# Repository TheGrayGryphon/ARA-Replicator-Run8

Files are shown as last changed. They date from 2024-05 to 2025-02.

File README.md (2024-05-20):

This is a complete build of a miniature rail-stand for use with railroad simulators.

Included in this repo:
1. Arduino IDE project for the hardware interface written found in the *miniRD_fw* directory.
2. Host "daemon" Python code used to send UDP data to the train simulator software known as Run8 (*Main.py* and *Run8.py*) - see *requirements.txt* for library dependencies.
3. KiCad project (right now, just a schematic) found in the *miniRDkicad* directory which details the electronics for the user controls.
4. Finally, some details on the mechanical bits including a layout of the button / lever mapping and links to the OnShape 3D model used to 3D-print the stand itself: https://cad.onshape.com/documents/ee68d1fb4ee2b8880d44aae3/w/7c6829b5f97449183b040dd5/e/efcd98333ec3d0d73e2c39b0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

See https://youtu.be/2jeVMYr9WaY?si=O1BfRgeKVzKorJtD for early demo.



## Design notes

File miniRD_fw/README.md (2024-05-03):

# MiniRD arduino "firmware"
 
Handles scanning the hardware (analog / digital) and interfacing to MiniRD daemon via serial port

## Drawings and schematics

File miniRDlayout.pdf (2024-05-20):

## Train brake lever

## Dynamic brake lever

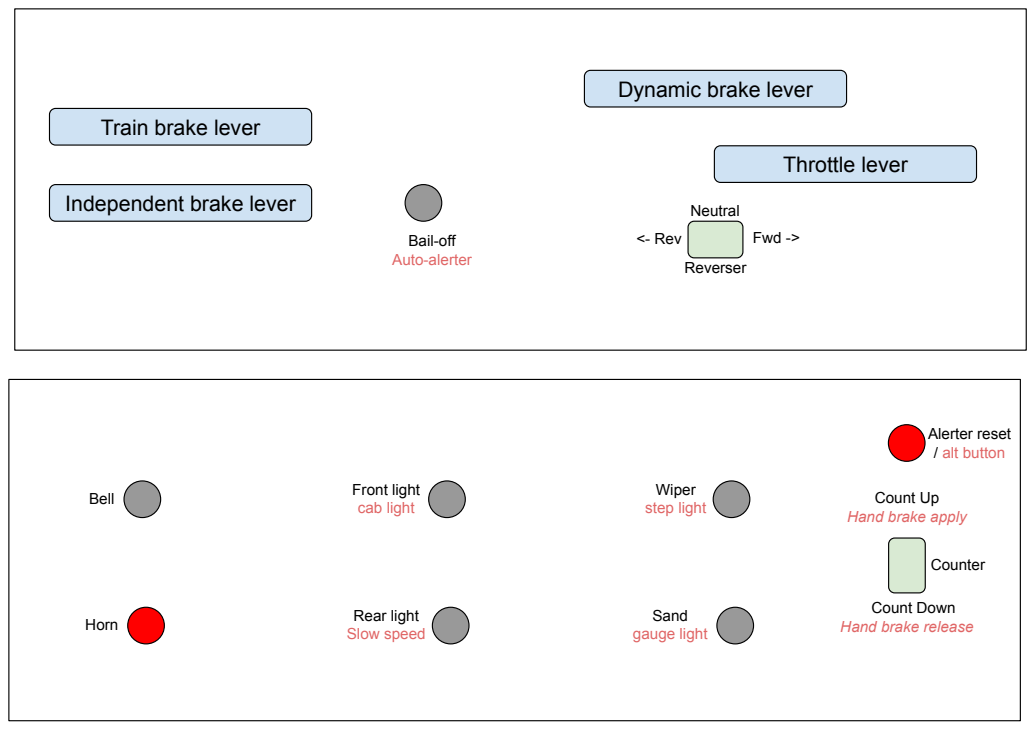
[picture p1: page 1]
Throttle lever; Reverser; Counter; <- Rev; Fwd ->; Neutral; Alerter reset / alt button; Wiper step light; Sand gauge light; Front light cab light; Rear light Slow speed; Bell; Horn; Bail-off Auto-alerter

Independent brake lever

Count Up
Hand brake apply

Count Down
Hand brake release

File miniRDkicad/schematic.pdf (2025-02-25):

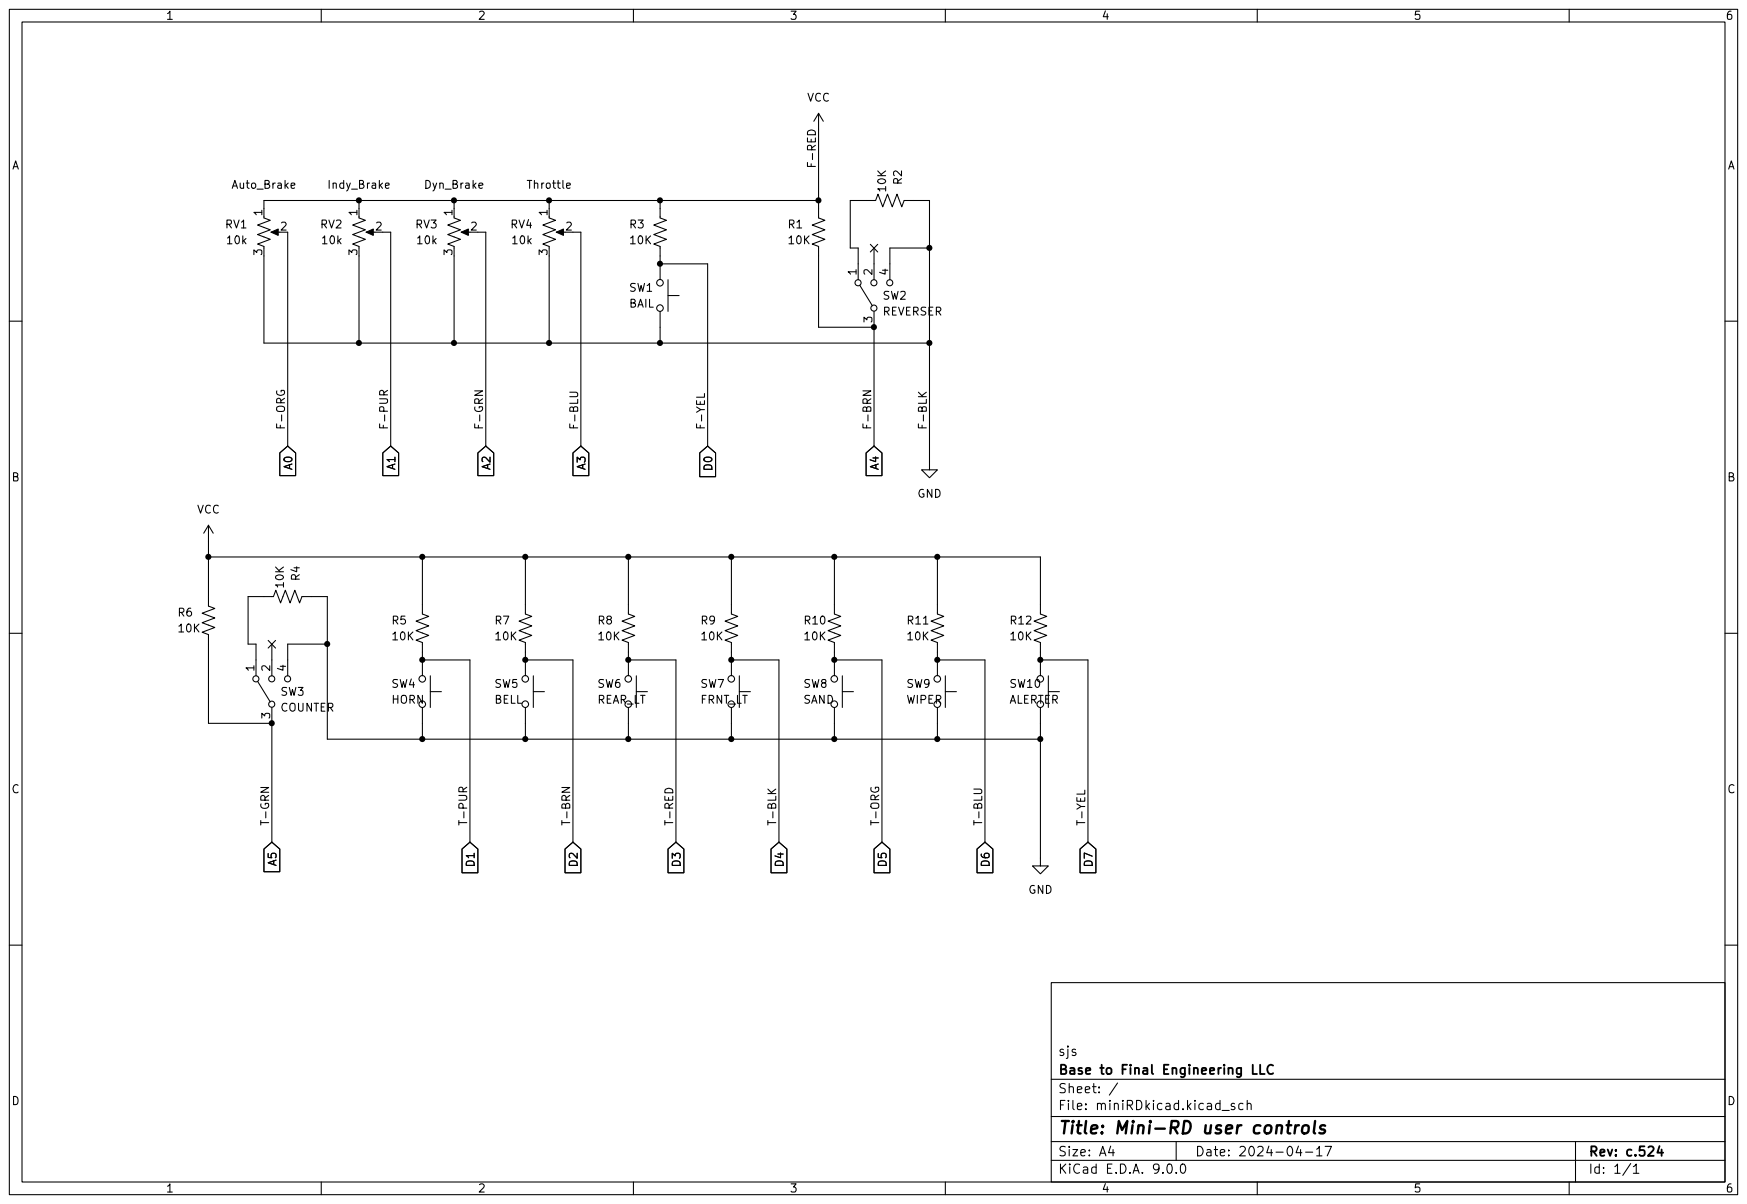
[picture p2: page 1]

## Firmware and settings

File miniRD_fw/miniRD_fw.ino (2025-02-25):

#include <Arduino.h>

// "Firmware" version info
const String version = "0225a";

// Analog break-point values for three-way switch inputs
// The three way switches (reverse, counter) use a voltage divider to signal their positions.
// The values below define how we determine the switch positions. 
const int low_bp = 250;
const int high_bp = 750;

// Hardware pin locations
// NOTE: The actual translation of these inputs to the UDP stream sent to the game client is defined in the 
//   miniRD server code.
// These are specific to the model of Arduino/ESP board being used
int autoBrakePin = A0;
int indyBrakePin = A1;
int dynamicBrakePin = A2;
int throttlePin = A3;
int reverserPin = A4;
int counterPin = A5;
// generic "pb" names are used here, but the original intended functions are shown in comments
int pb0Pin = 0;   // Bail 
int pb1Pin = 1;   // Horn
int pb2Pin = 5;   // Bell
int pb3Pin = 7;   // Front headlight
int pb4Pin = 9;   // Rear headlight
int pb5Pin = 10;  // Wiper toggle
int pb6Pin = 11;  // Sander
int pb7Pin = 12;  // Alerter

// Last known update value for analog inputs
int prev_auto_val = 0;
int prev_indy_val = 0;
int prev_dynamic_val = 0;
int prev_throttle_val = 0;

// Current value for analog inputs
int auto_val = 0;
int indy_val = 0;
int dynamic_val = 0;
int throttle_val = 0;
int reverser_val = 0;
int counter_val = 0;

// Enumerate reverser and counter (analog input) to integers
int reverser_pos, prev_reverser_pos = 1;  // 0 = reverse, 2 = neutral, 1 = fwd
int counter_pos, prev_counter_pos = 0;    // 2 = count down, 0 = center, 1 = count up (corresponds to Run8 API)

// pushbutton values (current and last)
bool pb0_val, pb0_lval = false;
bool pb1_val, pb1_lval = false;
bool pb2_val, pb2_lval = false;
bool pb3_val, pb3_lval = false;
bool pb4_val, pb4_lval = false;
bool pb5_val, pb5_lval = false;
bool pb6_val, pb6_lval = false;
bool pb7_val, pb7_lval = false;
unsigned long debounce_filter = 50; // Filter time in ms
unsigned long analog_filter = 50;
unsigned long pb0_time, pb1_time, pb2_time, pb3_time, pb4_time, pb5_time, pb6_time, pb7_time = 0;
unsigned long aut_time, ind_time, dyn_time, thr_time, rev_time, ctr_time = 0;

int incomingByte = 0; // for incoming serial data

void setup()
{
    Serial.begin(9600);
    pinMode(LED_BUILTIN, OUTPUT);
    digitalWrite(LED_BUILTIN, HIGH);
    pinMode(pb0Pin, INPUT);
    pinMode(pb1Pin, INPUT);
    pinMode(pb2Pin, INPUT);
    pinMode(pb3Pin, INPUT);
    pinMode(pb4Pin, INPUT);
    pinMode(pb5Pin, INPUT);
    pinMode(pb6Pin, INPUT);
    pinMode(pb7Pin, INPUT);
}

String scale(int input){
  int scaled_val = int(float(input-5)/1000 * 255);
  if (scaled_val > 255) { 
    scaled_val = 255;
    }
  if (scaled_val < 0) {
    scaled_val = 0;
  }
  return String(scaled_val);
}

void loop()
{
  // Read analog channels, output scaled values between (0,255)
  auto_val = analogRead(autoBrakePin);
  if (auto_val != prev_auto_val) {
    if ((millis() - aut_time) > analog_filter){ // reduce noise
      prev_auto_val = auto_val;
      aut_time = millis();
    }
  }

  indy_val = analogRead(indyBrakePin);
    if (indy_val != prev_indy_val) {
    if ((millis() - ind_time) > analog_filter){ // reduce noise
      prev_indy_val = indy_val;
      ind_time = millis();
    }
  }

  dynamic_val = analogRead(dynamicBrakePin);
    if (dynamic_val != prev_dynamic_val) {
    if ((millis() - dyn_time) > analog_filter){ // reduce noise
      prev_dynamic_val = dynamic_val;
      dyn_time = millis();
    }
  }

  throttle_val = analogRead(throttlePin);
    if (throttle_val != prev_throttle_val) {
    if ((millis() - thr_time) > analog_filter){ // reduce noise
      prev_throttle_val = throttle_val;
      thr_time = millis();
    }
  }

  // Read toggle switches via analog inputs and enumerate to ints
  reverser_val = analogRead(reverserPin);
    if (reverser_val < low_bp) {
      reverser_pos = 0;
    } else if (reverser_val > high_bp) {
      reverser_pos = 2;
    } else {
      reverser_pos = 1;
    }
    if (reverser_pos != prev_reverser_pos) {
    if ((millis() - rev_time) > analog_filter){ // reduce noise
      prev_reverser_pos = reverser_pos;
      rev_time = millis();
    }
  }

  counter_val = analogRead(counterPin);
    if (counter_val < low_bp) {
      counter_pos = 2;
    } else if (counter_val > high_bp) {
      counter_pos = 0;
    } else {
      counter_pos = 1;
    }
    if (counter_pos != prev_counter_pos) {
    if ((millis() - ctr_time) > analog_filter){ // reduce noise
      prev_counter_pos = counter_pos;
      ctr_time = millis();
    }
  }

  // Read digital channels
  pb0_val = digitalRead(pb0Pin);
  if (pb0_val != pb0_lval){
    if ((millis() - pb0_time) > debounce_filter){ // debounce
      pb0_lval = pb0_val;
      pb0_time = millis();
    }
  }

  pb1_val = digitalRead(pb1Pin);
  if (pb1_val != pb1_lval){
    if ((millis() - pb1_time) > debounce_filter){ // debounce
      pb1_lval = pb1_val;
      pb1_time = millis();
    }
  }

  pb2_val = digitalRead(pb2Pin);
  if (pb2_val != pb2_lval){
    if ((millis() - pb2_time) > debounce_filter){ // debounce
      pb2_lval = pb2_val;
      pb2_time = millis();
    }
  }

  pb3_val = digitalRead(pb3Pin);
  if (pb3_val != pb3_lval){
    if ((millis() - pb3_time) > debounce_filter){ // debounce
      pb3_lval = pb3_val;
      pb3_time = millis();
    }
  }

  pb4_val = digitalRead(pb4Pin);
  if (pb4_val != pb4_lval){
    if ((millis() - pb4_time) > debounce_filter){ // debounce
      pb4_lval = pb4_val;
      pb4_time = millis();
    }
  }

  pb5_val = digitalRead(pb5Pin);
  if (pb5_val != pb5_lval){
    if ((millis() - pb5_time) > debounce_filter){ // debounce
      pb5_lval = pb5_val;
      pb5_time = millis();
    }
  }

  pb6_val = digitalRead(pb6Pin);
  if (pb6_val != pb6_lval){
    if ((millis() - pb6_time) > debounce_filter){ // debounce
      pb6_lval = pb6_val;
      pb6_time = millis();
    }
  }

  pb7_val = digitalRead(pb7Pin);
  if (pb7_val != pb7_lval){
    if ((millis() - pb7_time) > debounce_filter){ // debounce
      pb7_lval = pb7_val;
      pb7_time = millis();
    }
  }

  // Check to see if a status update request has been initiated from the host (daemon).
  // Return status of all inputs as a comma delimited string in the following order:
  // <auto_brake>, <indy_brake>, <dynamic_brake>, <throttle>, <reverser>, <counter>, 
  // <bail_off>, <horn>, <bell>, <front_light>, <rear_light>, <wiper>, <sand>, <alerter>

  if (Serial.available() > 0) {
    incomingByte = Serial.read();
      if (incomingByte == 'r') {  // read request
        Serial.print(auto_val);
        Serial.print(",");
        Serial.print(indy_val);
        Serial.print(",");
        Serial.print(dynamic_val);
        Serial.print(",");
        Serial.print(throttle_val);
        Serial.print(",");
        Serial.print(reverser_pos);
        Serial.print(",");
        Serial.print(counter_pos);
        Serial.print(",");
        Serial.print(not(pb0_lval));
        Serial.print(",");
        Serial.print(not(pb1_lval));
        Serial.print(",");
        Serial.print(not(pb2_lval));
        Serial.print(",");
        Serial.print(not(pb3_lval));
        Serial.print(",");
        Serial.print(not(pb4_lval));
        Serial.print(",");
        Serial.print(not(pb5_lval));
        Serial.print(",");
        Serial.print(not(pb6_lval));
        Serial.print(",");
        Serial.println(not(pb7_lval));
        } 
      else if (incomingByte == 'I') { // Identification request
        Serial.print("miniRD,");
        Serial.println(version);
      }
    }
}

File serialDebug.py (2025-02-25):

import serial
import time
import serial.tools.list_ports


# List available COM ports
def list_com_ports():
    ports = serial.tools.list_ports.comports()
    print("\nAvailable COM ports:")
    for port in ports:
        print(f"  {port.device}")


# Try to connect to a COM port
def test_com_port(port, baudrate=9600, timeout=1):
    try:
        print(f"\nTrying to open {port} at {baudrate} baud...")
        ser = serial.Serial(port, baudrate, timeout=timeout)
        time.sleep(2)  # Allow time for initialization

        if ser.is_open:
            print(f"Successfully opened {port}")

            # Send a test message
            test_message = b"I\n"
            ser.write(test_message)
            print(f"Sent: {test_message.decode().strip()}")

            # Read response (if any)
            response = ser.readline().decode().strip()
            if response:
                print(f"Received: {response}")
            else:
                print("No response received.")

            # Close the port
            ser.close()
            print(f"Closed {port} successfully.")
        else:
            print(f"Failed to open {port}")

    except serial.SerialException as e:
        print(f"SerialException: {e}")
    except Exception as e:
        print(f"Unexpected error: {e}")


# Main script execution
if __name__ == "__main__":
    list_com_ports()
    port = input("\nEnter the COM port to test (e.g., COM3): ").strip()
    test_com_port(port)

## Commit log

2024-05-03 Initial commits
    [miniRDkicad.kicad_pcb, miniRDkicad.kicad_sch]
2024-05-03 Current functions of controls
    All functions are defined within the Python script (daemon).
2024-06-13 calibration initiated with alerter+horn
2025-02-25 fixed scaling issue. added delay to port openings
    [main.py]
2025-02-25 pdf of schematic for easier viewing
